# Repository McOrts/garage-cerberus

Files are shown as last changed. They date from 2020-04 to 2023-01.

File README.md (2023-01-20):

# Un barrera láser, LoRaWan y Docker para vigilar mi garage 

Se me ocurrió que alternativa para proteger el acceso a la plaza de garage comunitaria sin tener que instalar separaciones físicas. Se trata de visibilizar una barrera virtual que detecta y notifica intrusiones.

En esta primera iteración, el dispositivo sólo tiene un sensor de luz para detectar la interrupción de un haz láser a fin de avisar del paso de una persona. Más adelante podríamos incluir otros detectores de movimientos como un PIR (Passive infrared sensor). O la conexión son un sistema de grabación de imagen, por ejemplo.

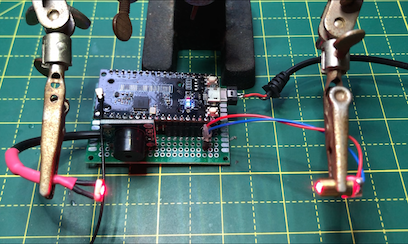
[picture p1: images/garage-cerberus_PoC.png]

El montaje se basa en un procesador ESP32 programado en C++ con las librerías de Arduino LMIC desarrolladas por IBM para los chips LoRa SX1272, SX1276 que son compatibles con muchas placas de prototipo LoRa montadas con micro-procesadores ESP8266. 

El sensor se basa en un LED láser y una foto-resistencia que se lee por un puerto de conversión Analógico/Digital. El programa ajusta los niveles de luz umbral al arrancar la placa. De manera que si se bloquea la luz se desencadena el proceso de aviso acústico y envío de mensaje de alerta por LoRa.

La parte de _backoffice_ es soportada por la plataforma [The Thing Networs (aka TTN)](https://www.thethingsnetwork.org/) e [IFTTT](https://ifttt.com/). La información finalmente se procesa en flujos de un programa en Node-RED que corre en un contenedor Docker sobre una Raspberry Pi 3B+ con el sistema operativo Raspbian. La foto de esta arquitectura sería esta:
<br>
<br>
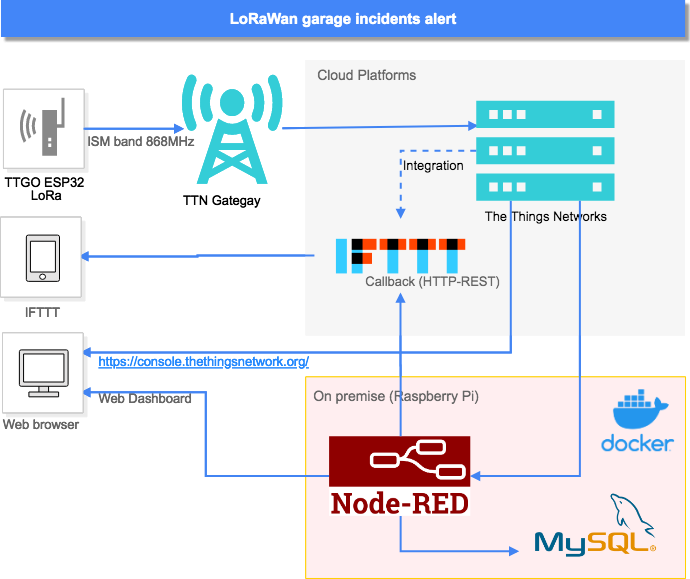
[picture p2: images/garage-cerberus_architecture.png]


## Demo
Demostración del proceso completo: detección y notificación: 
Demo de proceso completo, detección y notificación (https://youtu.be/qcct-dORirM)

## Material utilizado
- He utilizado la *placa* [TTGO LoRa32 V2.0 868 MHz](https://es.aliexpress.com/item/32850086038.html). Basada en el microprocesador ESP32 y en el chip LoRa SX1276, con WiFi y BlueTooth.
- La **fuente láser** es un pequeño [Diodo de 5mW y longitud de onda roja de 650 nm.](https://es.aliexpress.com/item/32400936169.html)
- El **receptor** es una resistencia sensible a la luz de 12mm [GL12528 LDR](https://es.aliexpress.com/item/32292338404.html)
- Y como **altavoz** un [buzzer pensado para montajes de Arduino](https://es.aliexpress.com/item/32849730395.html)
- Mini [**espejos** acrílicos](https://es.aliexpress.com/item/1861870525.html)

## El montaje
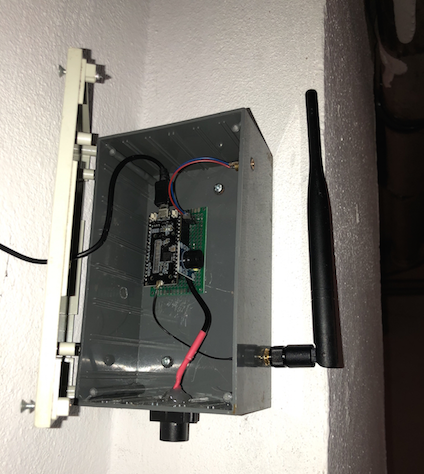
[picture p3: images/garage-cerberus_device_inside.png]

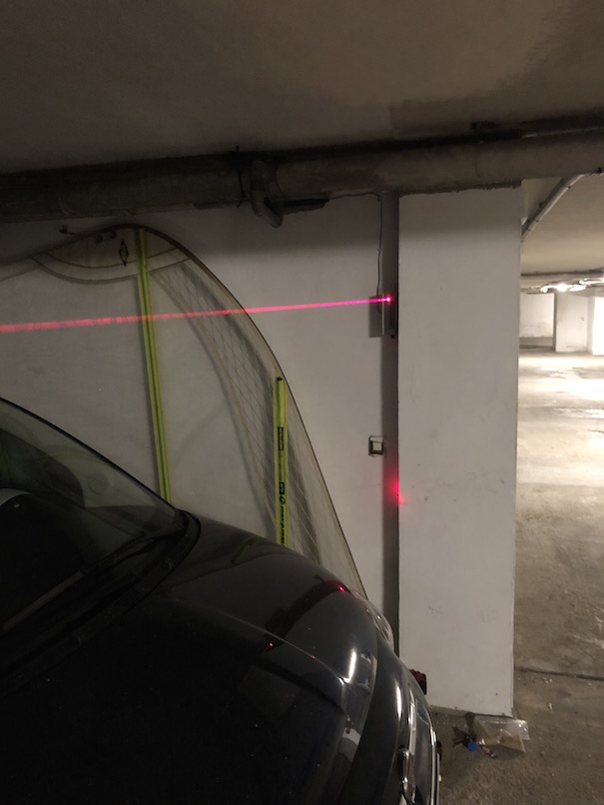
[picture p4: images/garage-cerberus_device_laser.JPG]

<br>

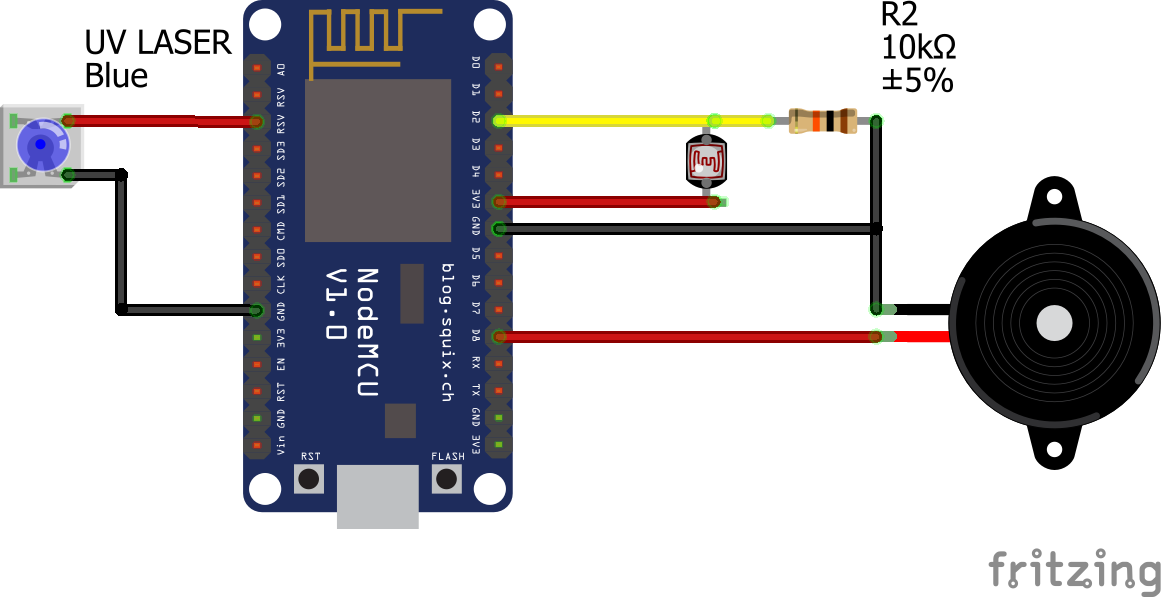
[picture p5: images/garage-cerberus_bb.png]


## Registro del sensor en la nube
Vamos a utilizar los servicios de TTN que enrutarán el mensaje desde el _gateway_ que reciba por radiofrecuencia el paquete de datos hasta el _endpoint_ que consumirá la aplicación que tome acción con la información contenida en la trama da datos. 

Este dispositivo es del tipo ABP (Activation-by-personalisation) lo que significa que se identificará en la red con un _DevAddr_ y una _Session key_ preconfigurada. Para ello tenemos que completar el registro de una aplicación y un dispositivo. Estos son los pasos a seguir:

### Registro de la aplicación
Los dispositivos como este sensor se comunican con la aplicación en la que han sido registrados. Para registras un dispositivo, primero hay que añadir una aplicación.

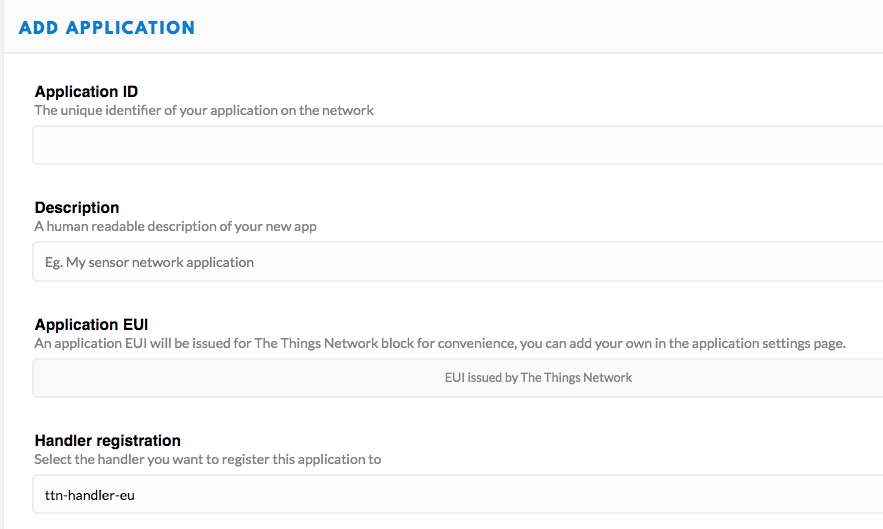
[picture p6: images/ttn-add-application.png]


En la consola, selecciona _APPLICATION_ y pulsa _add application_ en la siguiente pantalla. 
- Para el _Application ID_, elige un identificador único, en minúsculas, puedes usar caracteres alfanuméricos peor no guiones ´-´ consecutivos.
- Para  _Description_, elige la descripcion que prefieras.
- No hace falta poner nada en _Application EUI_ 
- En _Handler registration_ deja el valor predeterminado: ttn-handler-eu
- Presiona _Add Application_ para finalizar

Ahora seremos redirigidos a la página con la nueva aplicación añadida donde puedes encontrar la _app EUI_ y el _Access Keys_ generados.
<br>
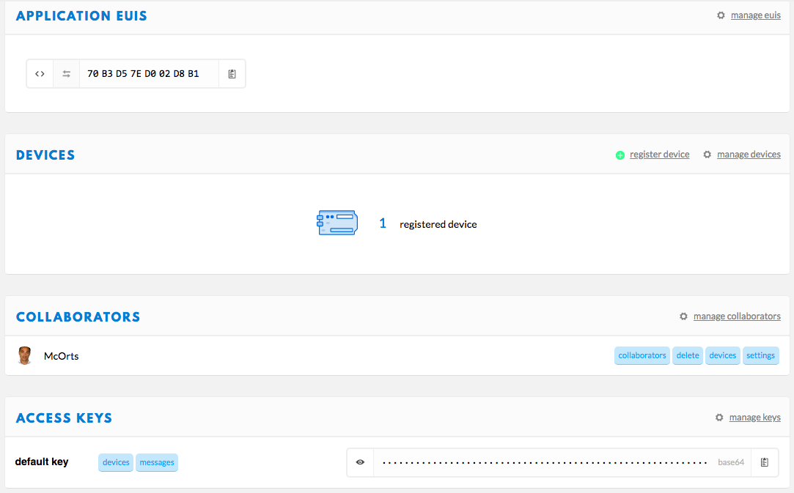
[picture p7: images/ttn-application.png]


### Registro del dispositivo

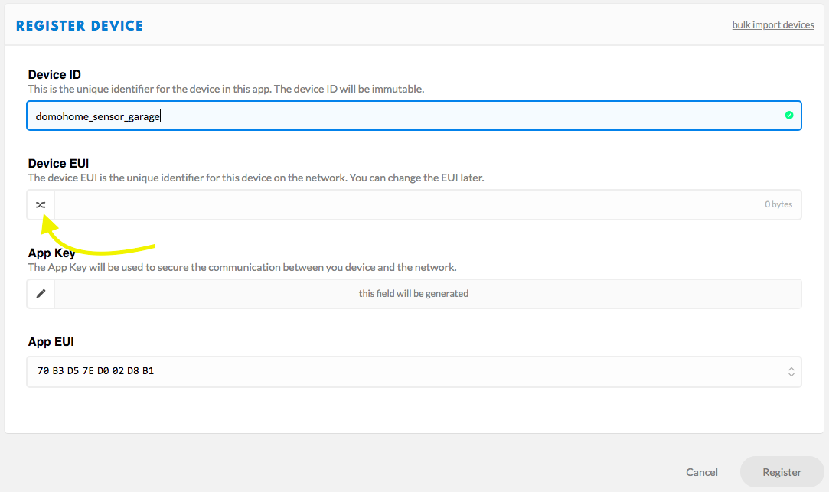
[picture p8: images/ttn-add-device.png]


En TTN un dispositivo (devide) representa la configuración de lo que también llama nodo (node) que a fin de cuentas es nuestro circuito. 
Al acceder al formulario de registro, únicamente tenemos que rellenar el _Device ID_ que será el nombre único de este nodo. Es preferible pulsar el icono marcado en la imagen para que se genere automáticamente el _Device EUI_.

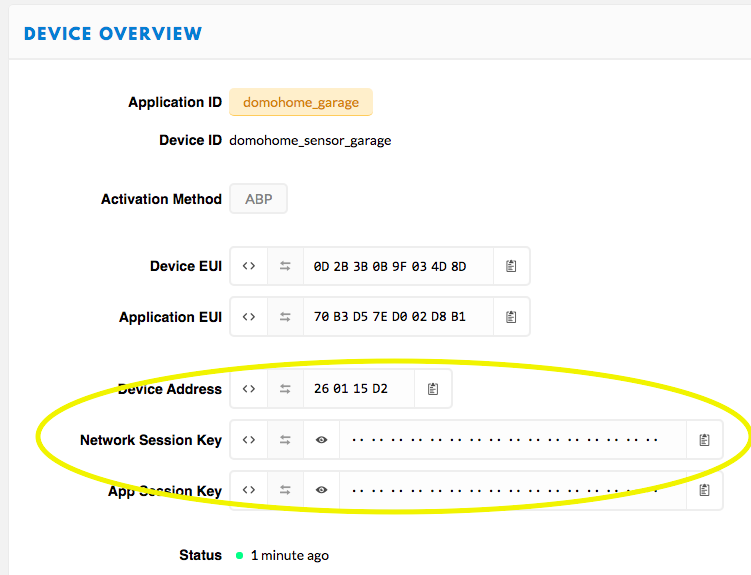
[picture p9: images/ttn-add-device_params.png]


<br>
<br>
<br>
<br>
<br>
<br>
<br>

Finalmente pulsaremos _Register_ y pulsaremos el icono con el nombre de nuestro nuevo dispositivo para ver sus datos de configuración. Aquí encontraremos los parámetros que necesitamos por ser un dispositivo de tipo ABP. Y que tendremos que pasar al fichero de configuración settings.h que se cargará en el _sketch_ del IDE de Arduino.
Pero el formato para las Keys es diferente. Encontrarás aquí una hoja excel (Encode_EUI.xlsx) que te facilitará esta tarea.

```
// TTN Configuration
// LoRaWAN NwkSKey, network session key provided by TTN Console (https://console.thethingsnetwork.org) in Device settings form:
static const PROGMEM u1_t NWKSKEY[16] = {0x8F,0xDA,......};
// LoRaWAN AppSKey, application session key provided by TTN Console (https://console.thethingsnetwork.org) in Device settings form:
static const u1_t PROGMEM APPSKEY[16] = {0xE5,0x0A,......};
// LoRaWAN end-device address (DevAddr)
static const u4_t DEVADDR = 0x12345678 ; // <-- Change this address for every node!

// Other params
const int update_time_alive = 150000;
const int PhotoCell = 2; 
const int Buzzer = 15;
```

### Formato de la trama
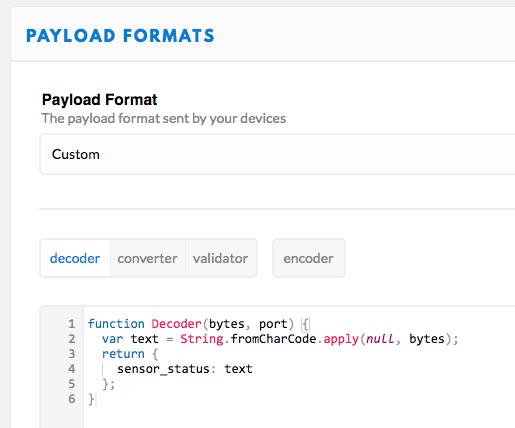
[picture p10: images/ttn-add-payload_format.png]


Tendremos que volver a la pantalla de _Application Overbiew_ para hacer una última configuración. Pulsando en la pestaña de _Payload Formats_ accedemos al formulario donde se permite poner un script para decodificar la trama de datos de nuestro mensaje LoRa. En nuestro caso este es el formato:

## Configuración servidor local

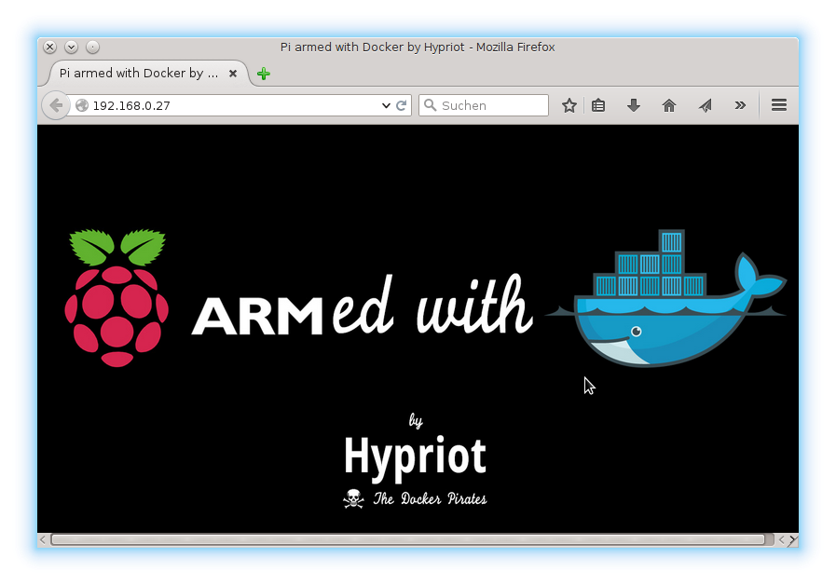
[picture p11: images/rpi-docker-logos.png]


La arquitectura elegida para el back y front está pensada para tener unos mínimos costes de operación y ser escalable. El uso de contenedores nos permitirá añadir nuevos dispositivos (Nodos TTN) rápidamente con su propio _dashboard_ Node-RED ejecutado en el mismo servidor. 

El servidor utilizado ha sido una Raspberry Pi 3B+. Actualmente no es el modelo más potente pero suficiente para ejecutar varios contenedores. Las tareas iniciales de configuración para instalar el sistema operativo Raspbian, y MySQL pueden ser fácilmente encontradas y son estándar. Los contenedores Docker y Node-RED con todos sus complementos necesarios para que se pueda ejecutar el flujo completo. Los describo a continuación.

### Instalación de contenedores
Para estas configuraciones me he basado en el documento: [The easy way to set up Docker on a Raspberry Pi](https://www.freecodecamp.org/news/the-easy-way-to-set-up-docker-on-a-raspberry-pi-7d24ced073ef/). Aquí resumo los pasos a seguir:

1. Instalar Docker en RPI:
```
sudo groupadd docker
sudo gpasswd -a $USER docker newgrp docker
docker run hello-world
```
2. Se crea el contenedor. Tendremos que mapear con puertos de salida diferentes, 1881 para este contenedor. A fin de que no coincida con los otros. 
```
docker run -d -it -p 1881:1880 --name domohome-garage  nodered/node-red
```

### Complementos de Node-RED
La aplicación Node-RED no incluye por defecto los nodos que necesitaremos para integrarnos con TTN, con MySQL o para mostrar un interface de usuario, los _dashboard_. En principio, todos se podrían instalar desde la opción _Manage Palette_ de la aplicación de administración a la que deberíamos acceder en la dirección del tipo: http://192.168.1.???:1881

**Nodos de _dashboard_**

Instalación estándar. Buscando el modulo ¨node-red-dashboard¨ en _install_ desde la opción de menú de _Manage Palette_ de la aplicación.

**Nodos integración con TTN**

Necesitaremos acceder al contenedor con una sesión SSH [Más info aquí](https://phoenixnap.com/kb/how-to-ssh-into-docker-container)
```
docker exec -it domohome-garage /bin/bash
```
Instalaremos ahora los nodos con el gestor de paquetes npm:
```
npm install node-red-contrib-ttn
```

**Nodos MySQL**

Desde la sesión SSH anterior ejecutamos:
```
npm install node-red-node-mysql
```
Para ampliar información sobre el uso y ejemplos la web de TTN tiene esta página: https://www.thethingsnetwork.org/docs/applications/nodered/

## Aplicación cliente
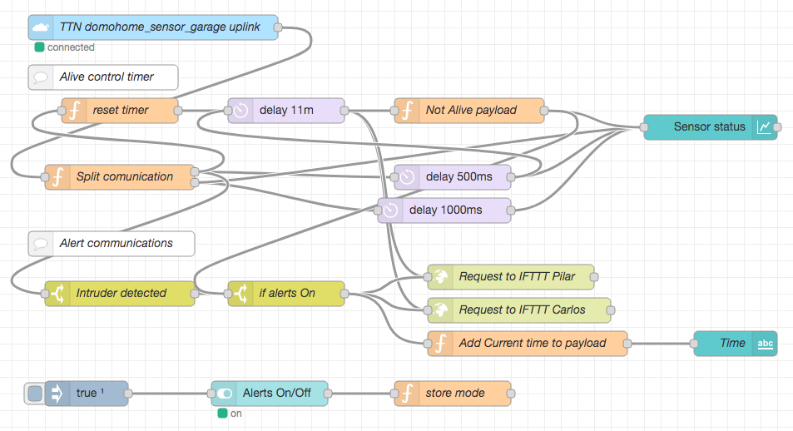
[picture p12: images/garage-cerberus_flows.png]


En el flujo de Node-RED se trata y muestra gráficamente los mensajes entregados por el servicio TTN. El _payload_ del mensaje contiene dos valores diferentes: ¨alert¨ cuando el haz láser es interrumpido y ¨alive¨ cada 10 minutos. Además se incluye una lógica para mostrar un estado de no disponible cuando en 11 minutos no ha llegado mensaje alguno.

Para importar el flujo deberemos acceder a la aplicación Node-RED que tenemos arrancada en el Docker en una dirección del tipo http://192.168.1.???:1881. Encontraremos la opción de importar pulsando el botón de menú tipo hamburguesa. Lo más fácil es copiar al portapapeles de equipo el contenido del fichero garage-cerberus_flows.json y pegarlo en la pantalla:
<br>
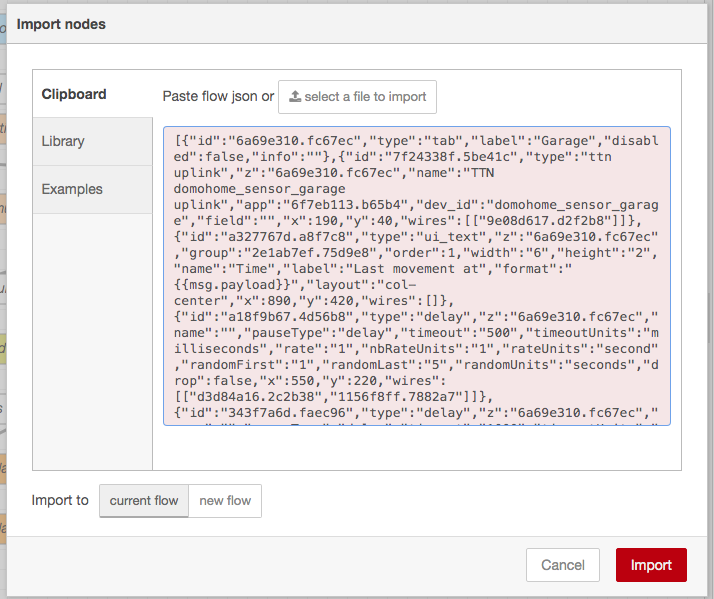
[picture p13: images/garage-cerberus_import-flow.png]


Tras pulsar el botón de ¨import¨ tendrás la vista de los nodos y los flujos. Pero hay tres de ellos que no están correctamente configurados.

### Configurar dispositivo TTN
Abre las propiedades del nodo **TTN domohome_sensor_garage uplink** y busca los nombres y la Key en la consola de TTN según las siguientes correspondencias:
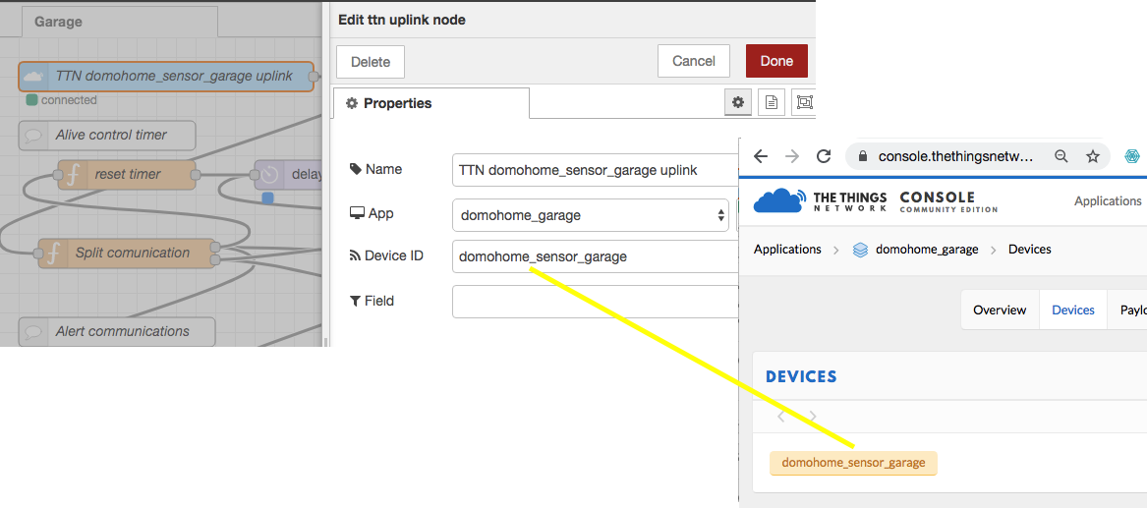
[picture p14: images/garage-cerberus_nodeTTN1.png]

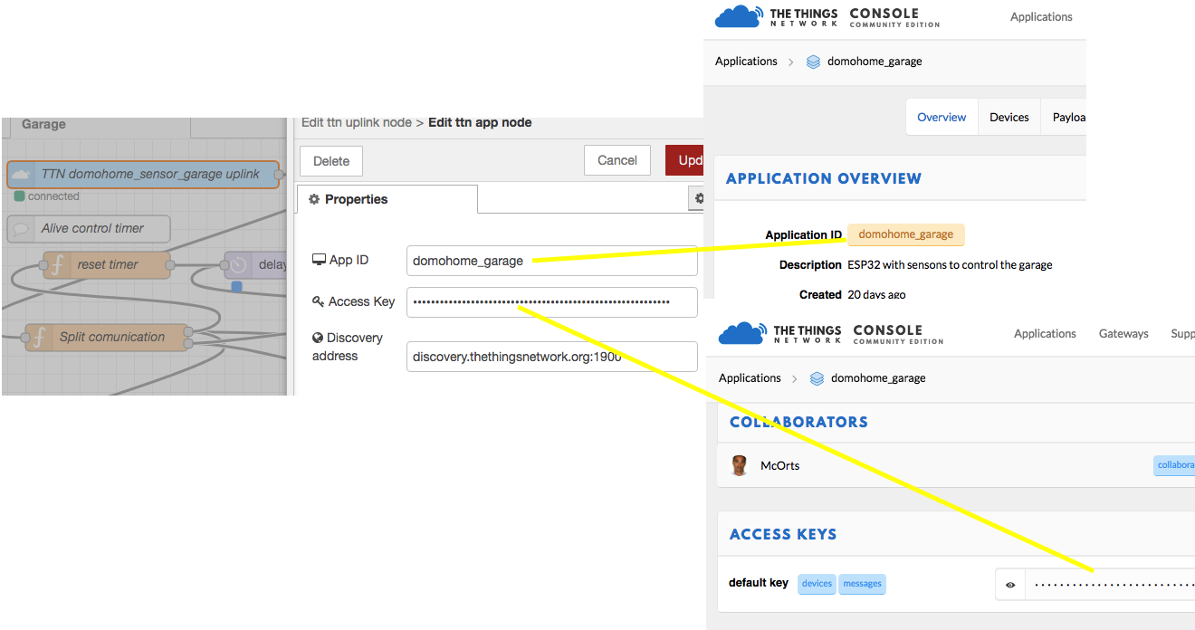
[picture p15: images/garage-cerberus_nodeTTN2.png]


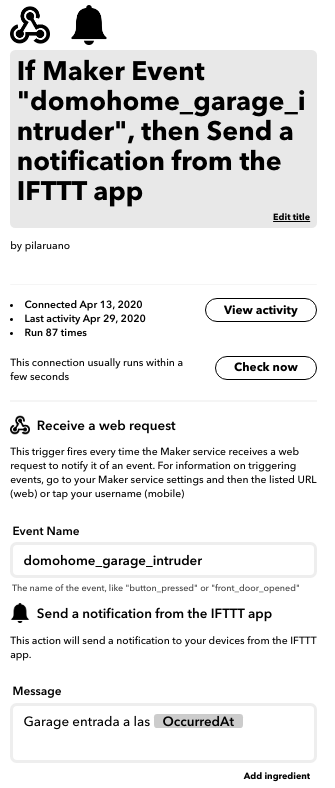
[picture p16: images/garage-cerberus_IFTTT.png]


### Configurar integración con IFTTT
La integración con IFTTT (If This Then That) está montada con una sencilla llamada a su _endpoint_ REST utilizando en nodo tipo _http request_ con el siguiente formato. 
<br>
```
https://maker.ifttt.com/trigger/domohome_garage_intruder/with/key/???????????
```
<br>
Donde sustituiremos las interrogantes por la Key que encontramos en esta configuración del componente Maker _Webhooks_ en IFTTT. Se encuentra siguiendo esta ruta:
- Configuración de usuario. Account
- My services
- webhooks
- documentation
Que configuraremos para recibir el evento disparar los avisos nativos en nuestra móvil a fin de tener notificación de la alarma.

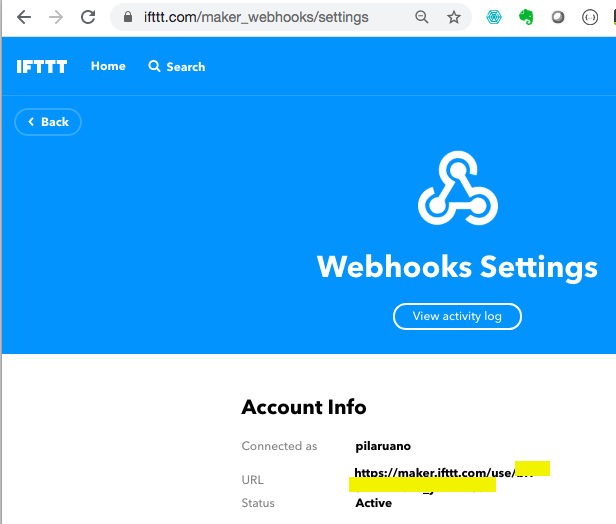
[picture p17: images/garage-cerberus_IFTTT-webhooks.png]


### Configurar nodo MySQL
Deberemos recoger toda la información de la cadena de conexión a nuestra BBDD MySQL externa a servidor RPI. Usuario, password, puerto, host... y completar la configuración de la _database_ del nodo MySQL.

### Dashboard 
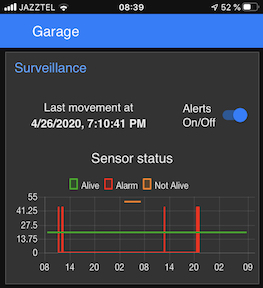
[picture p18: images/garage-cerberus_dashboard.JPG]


El resultado final es una pantalla responsiva donde se nos muestra el último evento, el histórico y la posibilidad de desactivar los avisos. Accederemos con la misma URL que para la administración pero con el sufijo /ui: http://192.168.1.???:1881/ui

### Pendiente: activación OTAA para TTN V3
https://blog.squix.org/2021/07/ttgo-lora32-v1-0-with-ttn-v3-and-otaa.html

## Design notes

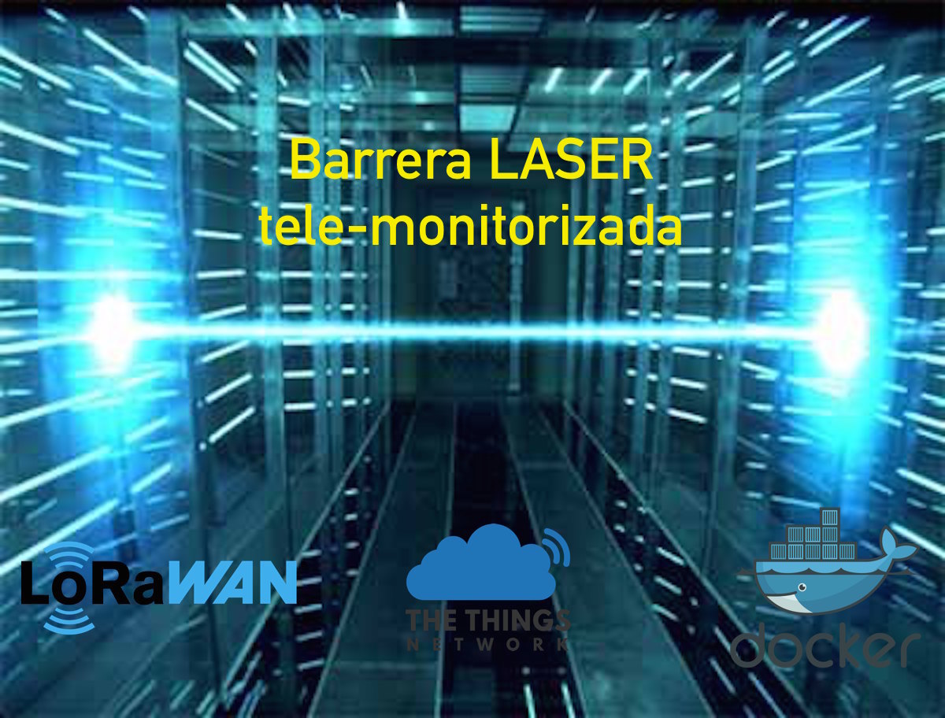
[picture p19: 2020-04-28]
images/garage-cerberus_poster.jpg

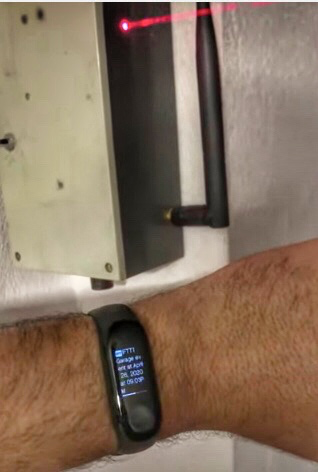
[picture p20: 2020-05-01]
images/garage-cerberus_demo.png

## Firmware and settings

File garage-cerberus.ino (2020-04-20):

/*******************************************************************************
 * Author: Carlos Orts 
 *         @mcorts
 *
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
 * This example sends a valid LoRaWAN packet with payload "Intruder" or "Alive",
 * using frequency and encryption settings matching those of
 * the The Things Network.
 *
 * This uses ABP (Activation-by-personalisation), where a DevAddr and
 * Session keys are preconfigured (unlike OTAA, where a DevEUI and
 * application key is configured, while the DevAddr and session keys are
 * assigned/generated in the over-the-air-activation procedure).
 *
 * Note: LoRaWAN per sub-band duty-cycle limitation is enforced (1% in
 * g1, 0.1% in g2), but not the TTN fair usage policy (which is probably
 * violated by this sketch when left running for longer)!
 *
 * To use this sketch, first register your application and device with
 * the things network, to set or generate a DevAddr, NwkSKey and
 * AppSKey. And setup this keys in config.h 
 * Each device should have their own unique values for these fields.
 *
 *******************************************************************************/

#include <lmic.h>
#include <hal/hal.h>
#include <SPI.h>
#include <Wire.h>
#include "settings.h"

long lastMsg = 0;

// setup PWM params for Buzzer
int freq = 2000;
int channel = 0;
int resolution = 8;

//Set up some global variables for the light level an initial value.
int lightInit;  // initial value
int lightVal;   // light reading

// These callbacks are only used in over-the-air activation, so they are
// left empty here (we cannot leave them out completely unless
void os_getArtEui (u1_t* buf) { }
void os_getDevEui (u1_t* buf) { }
void os_getDevKey (u1_t* buf) { }

uint8_t mydata[] = "     ";
static osjob_t sendjob;

// Schedule TX every this many seconds (might become longer due to duty
// cycle limitations).
const unsigned TX_INTERVAL = 60;

// Pin mapping
const lmic_pinmap lmic_pins = {
    .nss = 18,
    .rxtx = LMIC_UNUSED_PIN,
    .rst = 14,
    .dio = {26, 33, 32},
};

void onEvent (ev_t ev) {
    Serial.print(os_getTime());
    Serial.print(": ");
    switch(ev) {
        case EV_SCAN_TIMEOUT:
            Serial.println(F("EV_SCAN_TIMEOUT"));
            break;
        case EV_BEACON_FOUND:
            Serial.println(F("EV_BEACON_FOUND"));
            break;
        case EV_BEACON_MISSED:
            Serial.println(F("EV_BEACON_MISSED"));
            break;
        case EV_BEACON_TRACKED:
            Serial.println(F("EV_BEACON_TRACKED"));
            break;
        case EV_JOINING:
            Serial.println(F("EV_JOINING"));
            break;
        case EV_JOINED:
            Serial.println(F("EV_JOINED"));
            break;
        case EV_RFU1:
            Serial.println(F("EV_RFU1"));
            break;
        case EV_JOIN_FAILED:
            Serial.println(F("EV_JOIN_FAILED"));
            break;
        case EV_REJOIN_FAILED:
            Serial.println(F("EV_REJOIN_FAILED"));
            break;
        case EV_TXCOMPLETE:
            Serial.println(F("EV_TXCOMPLETE (includes waiting for RX windows)"));
            if (LMIC.txrxFlags & TXRX_ACK)
              Serial.println(F("Received ack"));
            if (LMIC.dataLen) {
              Serial.println(F("Received "));
              Serial.println(LMIC.dataLen);
              Serial.println(F(" bytes of payload"));
            }
            // Schedule next transmission
            os_setTimedCallback(&sendjob, os_getTime()+sec2osticks(TX_INTERVAL), do_send);
            break;
        case EV_LOST_TSYNC:
            Serial.println(F("EV_LOST_TSYNC"));
            break;
        case EV_RESET:
            Serial.println(F("EV_RESET"));
            break;
        case EV_RXCOMPLETE:
            // data received in ping slot
            Serial.println(F("EV_RXCOMPLETE"));
            break;
        case EV_LINK_DEAD:
            Serial.println(F("EV_LINK_DEAD"));
            break;
        case EV_LINK_ALIVE:
            Serial.println(F("EV_LINK_ALIVE"));
            break;
         default:
            Serial.println(F("Unknown event"));
            break;
    }
}

void do_send(osjob_t* j){
    // Check if there is not a current TX/RX job running
    if (LMIC.opmode & OP_TXRXPEND) {
        Serial.println(F("OP_TXRXPEND, not sending"));
    } else {
        // Prepare upstream data transmission at the next possible time.
        LMIC_setTxData2(1, mydata, sizeof(mydata)-1, 0);
        Serial.println(F("Packet queued"));
    }
    // Next TX is scheduled after TX_COMPLETE event.
}

void start_send() {
    // LMIC init
    os_init();
    // Reset the MAC state. Session and pending data transfers will be discarded.
    LMIC_reset();

    // Set static session parameters. Instead of dynamically establishing a session
    // by joining the network, precomputed session parameters are be provided.
    #ifdef PROGMEM
    // On AVR, these values are stored in flash and only copied to RAM
    // once. Copy them to a temporary buffer here, LMIC_setSession will
    // copy them into a buffer of its own again.
    uint8_t appskey[sizeof(APPSKEY)];
    uint8_t nwkskey[sizeof(NWKSKEY)];
    memcpy_P(appskey, APPSKEY, sizeof(APPSKEY));
    memcpy_P(nwkskey, NWKSKEY, sizeof(NWKSKEY));
    LMIC_setSession (0x1, DEVADDR, nwkskey, appskey);
    #else
    // If not running an AVR with PROGMEM, just use the arrays directly
    LMIC_setSession (0x1, DEVADDR, NWKSKEY, APPSKEY);
    #endif

    #if defined(CFG_eu868)
    // Set up the channels used by the Things Network, which corresponds
    // to the defaults of most gateways. Without this, only three base
    // channels from the LoRaWAN specification are used, which certainly
    // works, so it is good for debugging, but can overload those
    // frequencies, so be sure to configure the full frequency range of
    // your network here (unless your network autoconfigures them).
    // Setting up channels should happen after LMIC_setSession, as that
    // configures the minimal channel set.
    // NA-US channels 0-71 are configured automatically
    LMIC_setupChannel(0, 868100000, DR_RANGE_MAP(DR_SF12, DR_SF7),  BAND_CENTI);      // g-band
    LMIC_setupChannel(1, 868300000, DR_RANGE_MAP(DR_SF12, DR_SF7B), BAND_CENTI);      // g-band
    LMIC_setupChannel(2, 868500000, DR_RANGE_MAP(DR_SF12, DR_SF7),  BAND_CENTI);      // g-band
    LMIC_setupChannel(3, 867100000, DR_RANGE_MAP(DR_SF12, DR_SF7),  BAND_CENTI);      // g-band
    LMIC_setupChannel(4, 867300000, DR_RANGE_MAP(DR_SF12, DR_SF7),  BAND_CENTI);      // g-band
    LMIC_setupChannel(5, 867500000, DR_RANGE_MAP(DR_SF12, DR_SF7),  BAND_CENTI);      // g-band
    LMIC_setupChannel(6, 867700000, DR_RANGE_MAP(DR_SF12, DR_SF7),  BAND_CENTI);      // g-band
    LMIC_setupChannel(7, 867900000, DR_RANGE_MAP(DR_SF12, DR_SF7),  BAND_CENTI);      // g-band
    LMIC_setupChannel(8, 868800000, DR_RANGE_MAP(DR_FSK,  DR_FSK),  BAND_MILLI);      // g2-band
    // TTN defines an additional channel at 869.525Mhz using SF9 for class B
    // devices' ping slots. LMIC does not have an easy way to define set this
    // frequency and support for class B is spotty and untested, so this
    // frequency is not configured here.
    #elif defined(CFG_us915)
    // NA-US channels 0-71 are configured automatically
    // but only one group of 8 should (a subband) should be active
    // TTN recommends the second sub band, 1 in a zero based count.
    // https://github.com/TheThingsNetwork/gateway-conf/blob/master/US-global_conf.json
    LMIC_selectSubBand(1);
    #endif

    // Disable link check validation
    LMIC_setLinkCheckMode(0);

    // TTN uses SF9 for its RX2 window.
    LMIC.dn2Dr = DR_SF9;

    // Set data rate and transmit power for uplink (note: txpow seems to be ignored by the library)
    LMIC_setDrTxpow(DR_SF7,14);

    // Start job
    do_send(&sendjob);
}

void setup() {
    Serial.begin(115200);
    Serial.println(F("Starting"));

    ledcSetup(channel, freq, resolution);
    ledcAttachPin(Buzzer, channel);
    Serial.println("BUZZER initialized");
  
    lightInit = analogRead(PhotoCell);
    //we will take a single reading from the light sensor and store it in the lightCal        
    //variable. This will give us a prelinary value to compare against in the loop

    //Part of buzzer tones
    for (int i = 0; i < Buzzer; i++) 
      {
    }

    #ifndef ESP8266
    while (!Serial); // for Leonardo/Micro/Zero
    #endif

    #ifdef VCC_ENABLE
    // For Pinoccio Scout boards
    pinMode(VCC_ENABLE, OUTPUT);
    digitalWrite(VCC_ENABLE, HIGH);
    delay(1000);
    #endif
}

void loop() {
  // Read Photocell
  lightVal = analogRead(PhotoCell); // read the current light levels
  
  //if lightVal is less than our initial reading withing a threshold then it is dark.
  Serial.print(lightVal); Serial.print (" - "); Serial.print(lightInit); Serial.print (" = "); Serial.println(lightVal-lightInit);
  if(lightVal - lightInit < 500)  
  {
    Serial.println("LASER beam interrupted");
    Serial.println ("Transmiting");
    
    mydata[0]='A';mydata[1]='l';mydata[2]='a';mydata[3]='r';mydata[4]='m'; 
    start_send();

    // Alarm sound
    ledcWrite(channel, 255); // Set maximum volume
    for (int i = 1; i < 5; i++)
    {
      ledcWriteTone(channel, 6005);
      delay(250);
      ledcWriteTone(channel, 755);
      delay(250);
      Serial.print (i);
    }
    ledcWrite(channel, 0); // Set minimum volume
    delay (30000);
    // End tone
    ledcWrite(channel, 255); // Set maximum volume
    delay(250);
    ledcWriteTone(channel, 755);
    delay(250);
    ledcWriteTone(channel, 6005);
    ledcWrite(channel, 0); // Set minimum volume
  }
  long now_alive = millis();
  if (now_alive - lastMsg > update_time_alive) {
    lastMsg = now_alive;
    mydata[0]='A';mydata[1]='l';mydata[2]='i';mydata[3]='v';mydata[4]='e'; 
    start_send();
  }
}
